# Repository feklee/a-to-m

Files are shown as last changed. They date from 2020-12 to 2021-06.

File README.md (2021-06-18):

Introduction
============

A-to-M is an experimental construction system: Atoms (*A*) are
assembled *to* form molecules (*M*).

A molecule is powered with a USB-C adapter. This adapter is also used
to program individual atoms.

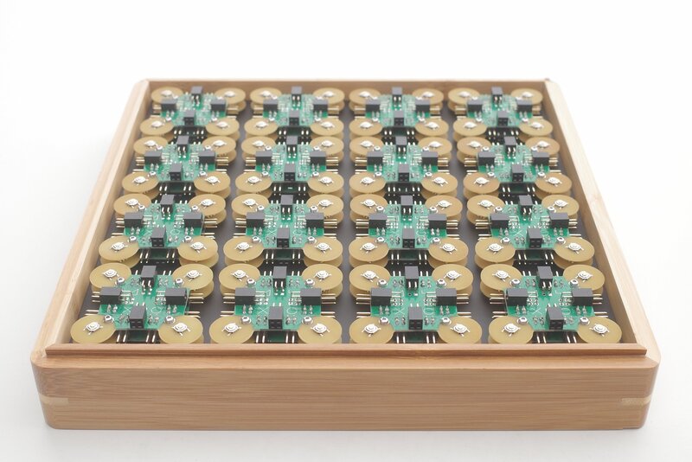
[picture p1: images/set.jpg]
Set


Design guidelines
=================

For areas without solder mask, don’t use components smaller than 0603
and don’t put traces too close. A clearance of 0.35 mm is good.

MiniCore
========

For a good experience, i.e. fast power up of an atom upon connection,
install [MiniCore][1] as boot loader.

Examples
========

Atomic tree
-----------

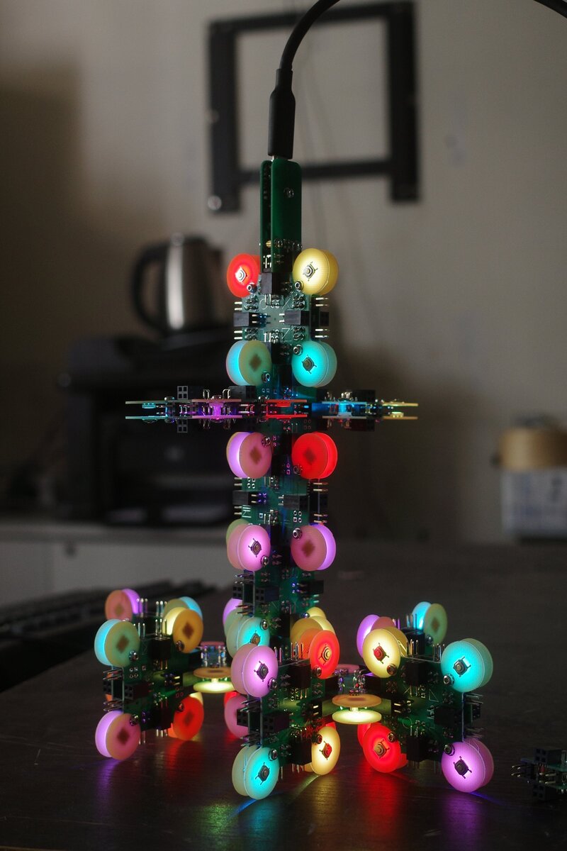
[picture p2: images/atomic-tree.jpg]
Atomic tree


Sequencer
---------

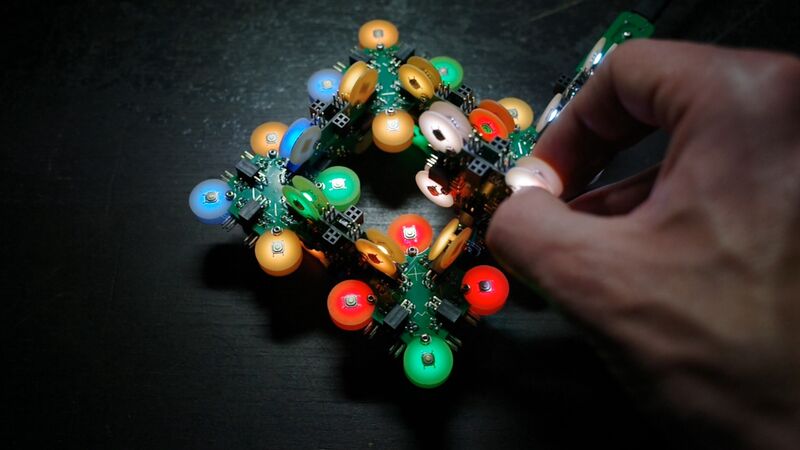
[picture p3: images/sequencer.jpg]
Sequencer
[][2]  
[Video][2]

License
=======

Except where noted otherwise, files are licensed under the WTFPL.

Copyright © 2020 [Felix E. Klee](felix.klee@inka.de)

This work is free. You can redistribute it and/or modify it under the
terms of the Do What The Fuck You Want To Public License, Version 2,
as published by Sam Hocevar. See the COPYING file for more details.

[1]: https://github.com/MCUdude/MiniCore
[2]: https://archive.org/details/a-to-m-sequencer

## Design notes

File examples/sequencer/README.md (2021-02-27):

Example of a simple sequencer. Connect atoms, then push two buttons
simultaneously on the first atom to send a pulse through the network.
It propagates at a rate of 240 beats per atom. Each atom that is
pulsed, plays a note. Configure the note by pushing the buttons on an
atom.

Buttons:

  * Release multiple: Create a pulse propagating through the network.
  
  * Button 1: Increase note.

  * Button 2: Change duration.
  
  * Button 3: Decrease note.
  
  * Button 4: Change waveform.

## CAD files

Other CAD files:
adapter.3dm
atom.3dm

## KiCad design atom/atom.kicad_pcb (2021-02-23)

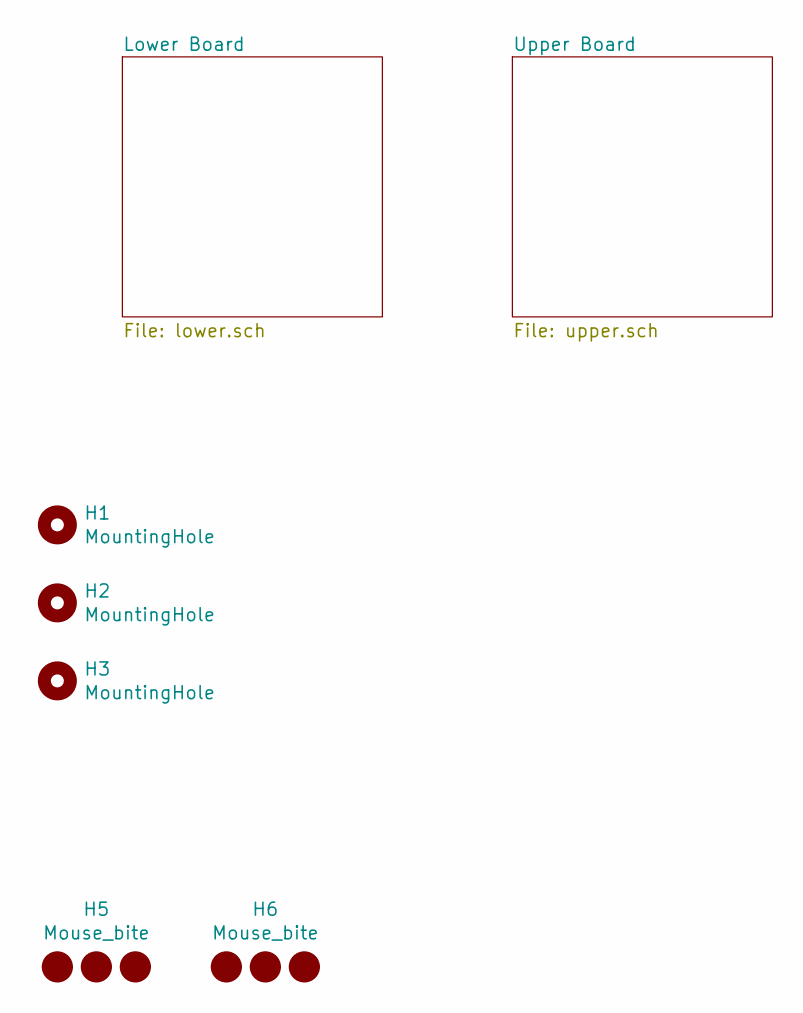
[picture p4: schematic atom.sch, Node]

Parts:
H1, H2, H3: MountingHole; JLCPCB-tooling-hole; JLCPCB BOM False
H5, H6: Mouse_bite; single_sided_tab_5mm; JLCPCB BOM False

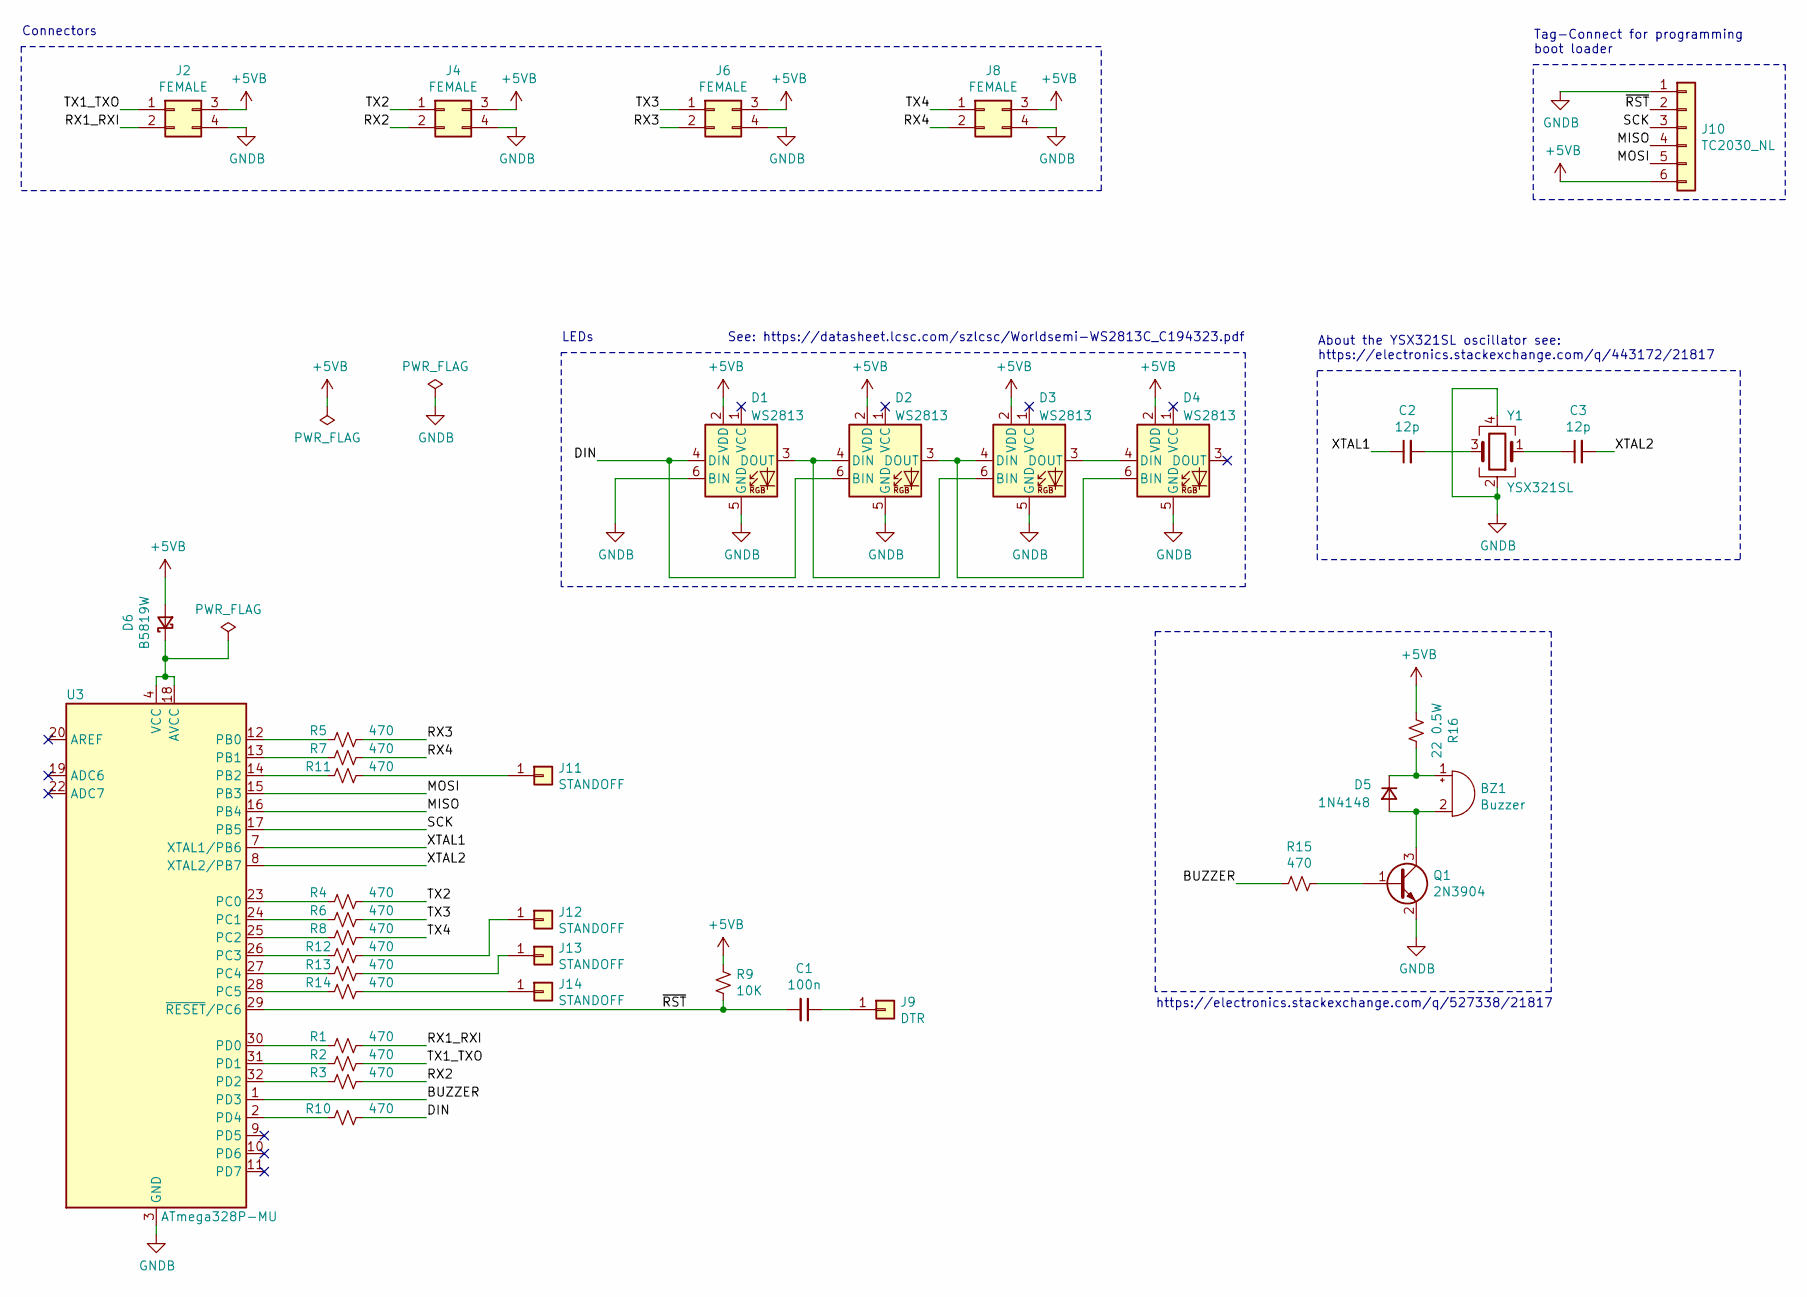
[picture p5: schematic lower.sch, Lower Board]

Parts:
BZ1: Buzzer; MLT-5020; MPN MLT-5020; LCSC Part C94598
C1: 100n; C_0402_1005Metric; MPN CL05B104KO5NNNC; LCSC Part C1525
C2, C3: 12p; C_0402_1005Metric; MPN 0402CG120J500NT; LCSC Part C1547
D1, D2, D3, D4: WS2813; bottom-leaf; MPN WS2813C; LCSC Part C194323
D5: 1N4148; D_SOD-323; MPN 1N4148WS-7-F; LCSC Part C60580
D6: B5819W; D_SOD-123
J2, J4, J6, J8: FEMALE; PinSocket_2x02_P2.54mm_Horizontal; MPN A2541HWR-2x2P; LCSC Part C239353
J9: DTR; PinHeader_1x01_P2.54mm_Vertical; JLCPCB BOM False
J10: TC2030_NL; Tag-Connect_TC2030-IDC-NL_2x03_P1.27mm_Vertical; JLCPCB BOM False
J11, J12, J13, J14: STANDOFF; MountingHole_2.2mm_M2_Pad_Via; JLCPCB BOM False
Q1: 2N3904; SOT-23; MPN PMBT3904,215; LCSC Part C8667
R1, R2, R3, R4, R5, R6, R7, R8, R10, R11, R12, R13, R14, R15: 470; R_0402_1005Metric; MPN 0402WGF4700TCE; LCSC Part C25117
R9: 10K; R_0402_1005Metric; MPN 0402WGF1002TCE; LCSC Part C25744
R16: 22 0.5W; R_2010_5025Metric; MPN 2010W2F220JT4S; LCSC Part C70404
U3: ATmega328P-MU; QFN-32-1EP_5x5mm_P0.5mm_EP3.1x3.1mm; MPN ATMEGA328P-MU; LCSC Part C783592
Y1: YSX321SL; MPN X322516MOB4SI; LCSC Part C12668

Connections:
+5VB: D1.2 (VDD), D2.2 (VDD), D3.2 (VDD), D4.2 (VDD), D6.2 (A), J2.3, J4.3, J6.3, J8.3, J10.6, R9.1, R16.2
/Lower Board/BUZZER: R15.2, U3.1 (PD3)
/Lower Board/DIN: D1.4 (DIN), D2.6 (BIN), R10.1
/Lower Board/MISO: J10.4, U3.16 (PB4)
/Lower Board/MOSI: J10.5, U3.15 (PB3)
/Lower Board/RX1_RXI: J2.2, R1.1
/Lower Board/RX2: J4.2, R3.1
/Lower Board/RX3: J6.2, R5.1
/Lower Board/RX4: J8.2, R7.1
/Lower Board/SCK: J10.3, U3.17 (PB5)
/Lower Board/TX1_TXO: J2.1, R2.1
/Lower Board/TX2: J4.1, R4.1
/Lower Board/TX3: J6.1, R6.1
/Lower Board/TX4: J8.1, R8.1
/Lower Board/XTAL1: C2.1, U3.7 (XTAL1/PB6)
/Lower Board/XTAL2: C3.2, U3.8 (XTAL2/PB7)
/Lower Board/~RST: C1.2, J10.2, R9.2, U3.29 (~RESET~/PC6)
GNDB: D1.5 (GND), D1.6 (BIN), D2.5 (GND), D3.5 (GND), D4.5 (GND), J2.4, J4.4, J6.4, J8.4, J10.1, Q1.2 (E), U3.3 (GND), U3.5 (GND), U3.21 (GND), U3.33 (GND), Y1.2, Y1.4
unnamed: BZ1.1 (-), D5.1 (K), R16.1
unnamed: BZ1.2 (+), D5.2 (A), Q1.3 (C)
unnamed: C1.1, J9.1
unnamed: C2.2, Y1.3
unnamed: C3.1, Y1.1
unnamed: D1.3 (DOUT), D2.4 (DIN), D3.6 (BIN)
unnamed: D2.3 (DOUT), D3.4 (DIN), D4.6 (BIN)
unnamed: D3.3 (DOUT), D4.4 (DIN)
unnamed: D6.1 (K), U3.4 (VCC), U3.6 (VCC), U3.18 (AVCC)
unnamed: J11.1, R11.1
unnamed: J12.1, R12.1
unnamed: J13.1, R13.1
unnamed: J14.1, R14.1
unnamed: Q1.1 (B), R15.1
unnamed: R1.2, U3.30 (PD0)
unnamed: R2.2, U3.31 (PD1)
unnamed: R3.2, U3.32 (PD2)
unnamed: R4.2, U3.23 (PC0)
unnamed: R5.2, U3.12 (PB0)
unnamed: R6.2, U3.24 (PC1)
unnamed: R7.2, U3.13 (PB1)
unnamed: R8.2, U3.25 (PC2)
unnamed: R10.2, U3.2 (PD4)
unnamed: R11.2, U3.14 (PB2)
unnamed: R12.2, U3.26 (PC3)
unnamed: R13.2, U3.27 (PC4)
unnamed: R14.2, U3.28 (PC5)

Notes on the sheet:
See: https://datasheet.lcsc.com/szlcsc/Worldsemi-WS2813C_C194323.pdf
LEDs
Connectors
About the YSX321SL oscillator see: https://electronics.stackexchange.com/q/443172/21817
Tag-Connect for programming boot loader
https://electronics.stackexchange.com/q/527338/21817

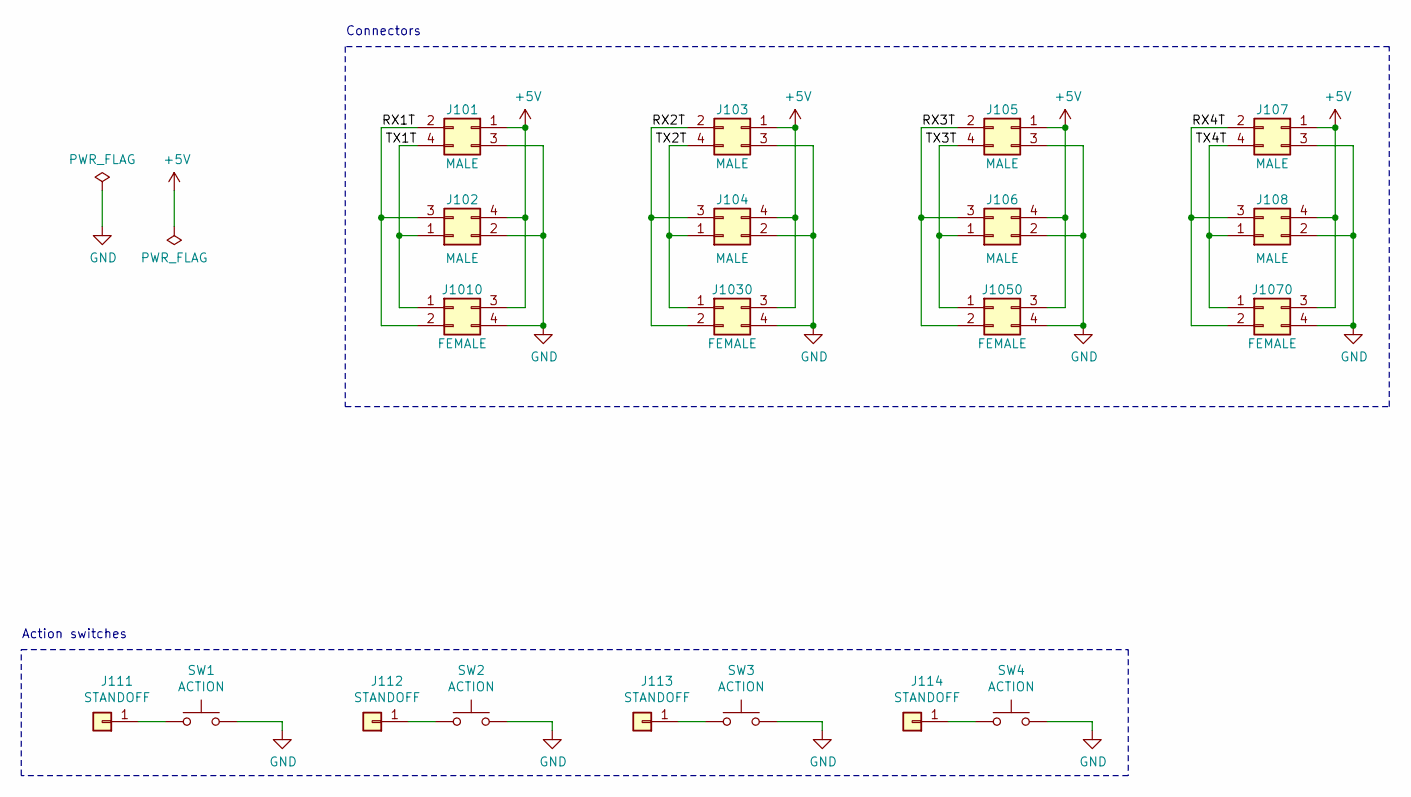
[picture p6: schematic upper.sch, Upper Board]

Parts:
J101, J103, J105, J107, J1010, J1030, J1050, J1070: MALE; PinHeader_2x02_P2.54mm_Horizontal; MPN A2541WR-2x2P; LCSC Part C239333
J102, J104, J106, J108: FEMALE; PinSocket_2x02_P2.54mm_Horizontal; MPN A2541HWR-2x2P; LCSC Part C239353
J111, J112, J113, J114: STANDOFF; MountingHole_2.2mm_M2_Pad_Via; JLCPCB BOM False
SW1, SW2, SW3, SW4: ACTION; top-leaf; MPN TS-1187A-B-A-B; LCSC Part C318884

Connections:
+5V: J101.1, J102.3, J103.1, J104.3, J105.1, J106.3, J107.1, J108.3, J1010.4, J1030.4, J1050.4, J1070.4
/Upper Board/RX1T: J101.2, J102.2, J1010.3
/Upper Board/RX2T: J103.2, J104.2, J1030.3
/Upper Board/RX3T: J105.2, J106.2, J1050.3
/Upper Board/RX4T: J107.2, J108.2, J1070.3
/Upper Board/TX1T: J101.4, J102.1, J1010.1
/Upper Board/TX2T: J103.4, J104.1, J1030.1
/Upper Board/TX3T: J105.4, J106.1, J1050.1
/Upper Board/TX4T: J107.4, J108.1, J1070.1
GND: J101.3, J102.4, J103.3, J104.4, J105.3, J106.4, J107.3, J108.4, J1010.2, J1030.2, J1050.2, J1070.2, SW1.2, SW2.2, SW3.2, SW4.2
unnamed: J111.1, SW1.1
unnamed: J112.1, SW2.1
unnamed: J113.1, SW3.1
unnamed: J114.1, SW4.1

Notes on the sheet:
Action switches
Connectors

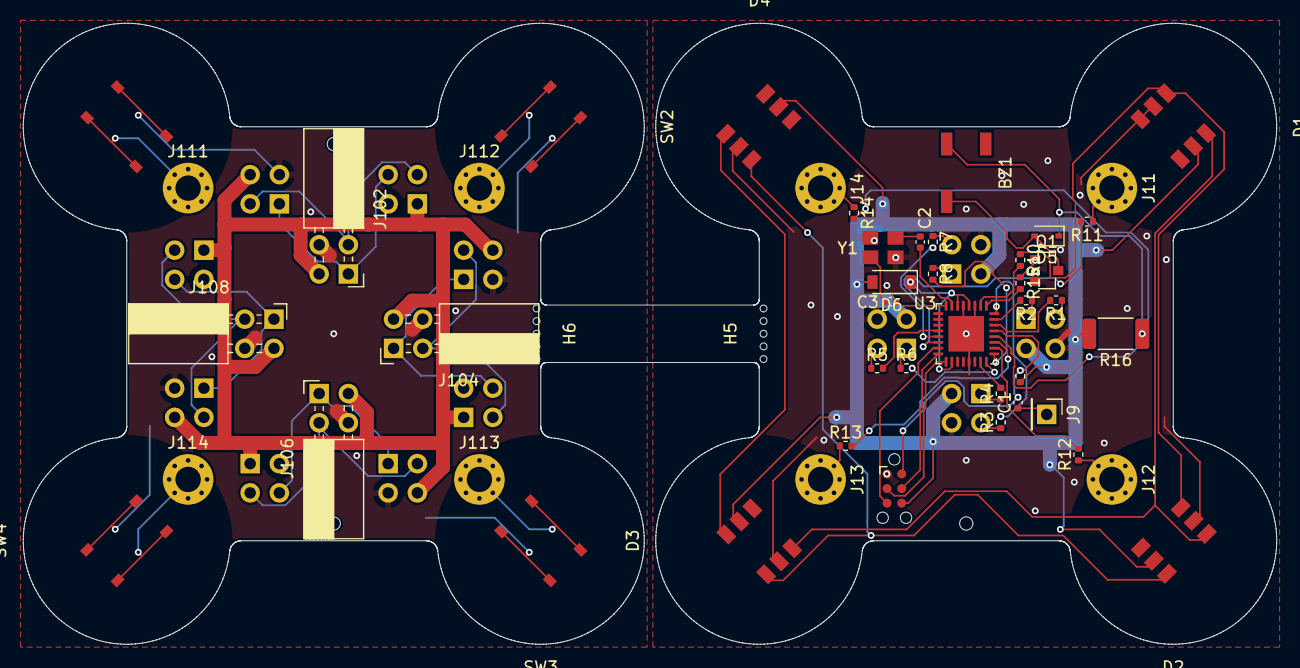
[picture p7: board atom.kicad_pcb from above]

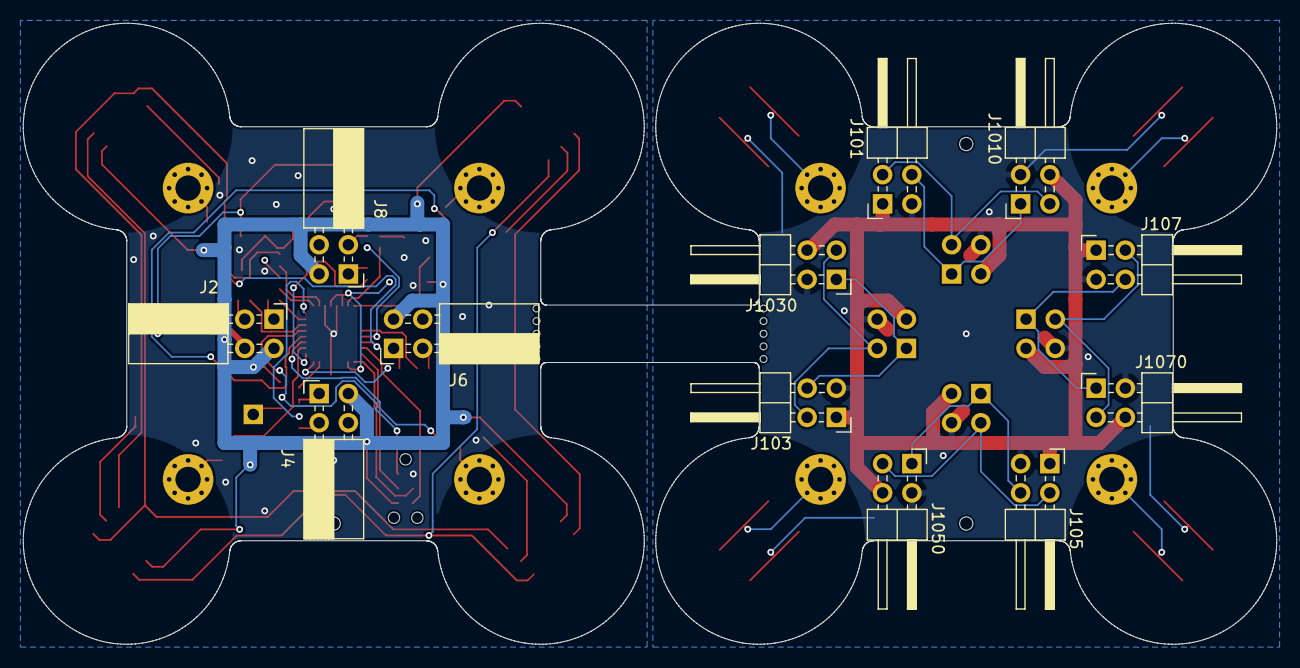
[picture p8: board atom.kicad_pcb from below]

Board: 2 copper layers, 109.0 x 54.0 mm, 64 parts (12 on the bottom side), 59 nets.

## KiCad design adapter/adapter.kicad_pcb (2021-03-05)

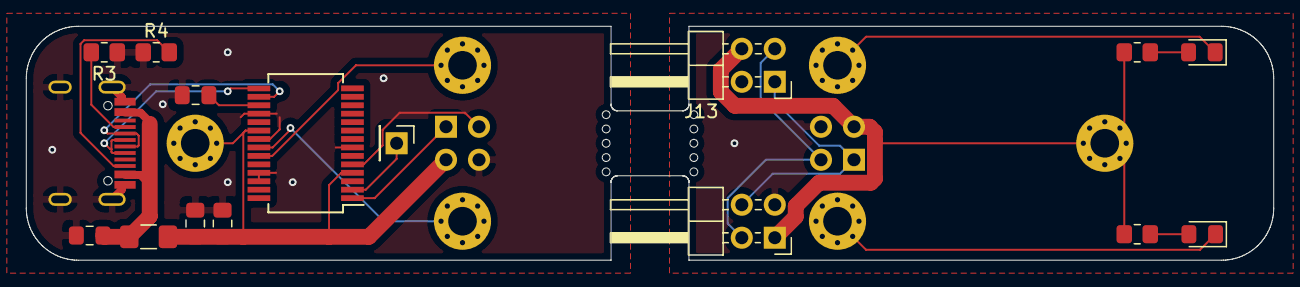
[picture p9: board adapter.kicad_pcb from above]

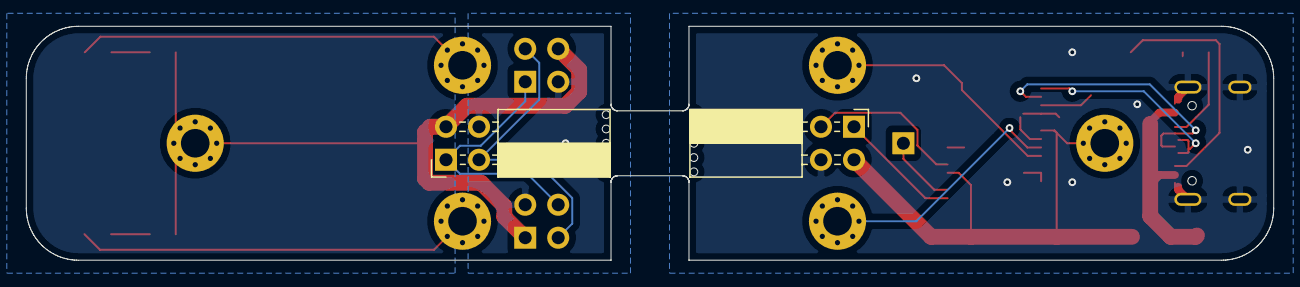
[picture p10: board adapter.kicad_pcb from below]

Board: 2 copper layers, 96.0 x 18.0 mm, 26 parts (2 on the bottom side), 21 nets.

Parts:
C1, C2, C3: 100n; C_0805_2012Metric_Pad1.15x1.40mm_HandSolder
C4: 4.7u; C_0805_2012Metric_Pad1.15x1.40mm_HandSolder
D1: Green; LED_0805_2012Metric_Pad1.15x1.40mm_HandSolder
D2: Red; LED_0805_2012Metric_Pad1.15x1.40mm_HandSolder
F1: Polyfuse_Small; Fuse_1206_3216Metric_Pad1.42x1.75mm_HandSolder
H1, H2: Mouse_bite; single_sided_tab_5mm
J2, J12: FEMALE; PinSocket_2x02_P2.54mm_Horizontal
J3, J4, J5, J14, J15, J16: STANDOFF; MountingHole_2.2mm_M2_Pad_Via
J6: USB_C_Receptacle_USB2.0; SOFNG_MC-311D
J7: DTR; PinHeader_1x01_P2.54mm_Vertical
J11, J13: MALE; PinHeader_2x02_P2.54mm_Horizontal
R1, R2: 1k; R_0805_2012Metric_Pad1.20x1.40mm_HandSolder
R3, R4: 5.1k; R_0805_2012Metric_Pad1.20x1.40mm_HandSolder
U1: FT232RL; SSOP-28_5.3x10.2mm_P0.65mm

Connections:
+5V: J11.1, J12.3, J13.4, J16.1, R1.1, R2.1
+5VB: C3.2, C4.1, F1.1, J2.3, J5.1, U1.4, U1.20
/Lower Board/D+: J6.A6, J6.B6, U1.15
/Lower Board/D-: J6.A7, J6.B7, U1.16
/Lower Board/DTR: J7.1, U1.2
/Lower Board/RXD: J2.2, U1.5
/Lower Board/RXLED: J4.1, U1.22
/Lower Board/TXD: J2.1, U1.1
/Lower Board/TXLED: J3.1, U1.23
/Lower Board/VBUS: C1.2, F1.2, J6.A4, J6.A9, J6.B4, J6.B9
/Upper Board/RX1T: J11.2, J12.2, J13.3
/Upper Board/TX1T: J11.4, J12.1, J13.1
GND: J11.3, J12.4, J13.2
GNDB: C1.1, C2.2, C3.1, C4.2, J2.4, J6.A1, J6.A12, J6.B1, J6.B12, J6.S1, R3.1, R4.1, U1.7, U1.18, U1.21, U1.25, U1.26
unnamed: C2.1, U1.17
unnamed: D1.1, J14.1
unnamed: D1.2, R1.2
unnamed: D2.1, J15.1
unnamed: D2.2, R2.2
unnamed: J6.A5, R3.2
unnamed: J6.B5, R4.2

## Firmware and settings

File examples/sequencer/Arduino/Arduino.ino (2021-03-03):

#include <FastLED.h>
#include <ezButton.h>

constexpr uint8_t buttonPinNos[] = {
  10, // PB2
  17, // PC3
  18, // PC4
  19 // PC5
};

constexpr uint8_t rxPinNos[] = {
  0, // RX1 = PD0 = PCINT16
  2, // RX2 = PD2 = PCINT18
  8, // RX3 = PB0 = PCINT0
  9 // RX4 = PB1 = PCINT1
};

constexpr uint8_t txPinNos[] = {
  1, // TX1 = PD1
  A0, // TX2 = PC0
  A1, // TX3 = PC1
  A2 // TX4 = PC2
};

constexpr uint8_t speakerPinNo = 3;

constexpr uint8_t ledPinNo = 4;
CRGB leds[4];

volatile bool pulseHasBeenReceived = false;
volatile uint8_t portThatReceivedPulse;

bool waitingForMultiButtonRelease = false;

constexpr uint8_t noOfDurations = 3;
uint16_t durations[noOfDurations] = { // in ms
  125,
  250,
  375
};
int8_t selectedDurationIndex = 1;

constexpr uint8_t noOfNotes = 10;
uint16_t frequencies[noOfNotes] = {
  2093, // C7
  2349, // D7
  2637, // E7
  3136, // G7
  3520, // A7
  4186, // C8
  4699, // D8
  5274, // E8
  6272, // G8
  7040 // A8
};
uint8_t selectedNote = 5;

constexpr uint8_t noOfWaveForms = 3;
struct {
  enum {silent, square, noise};
} waveForms;
uint8_t selectedWaveForm = waveForms.square;

struct {
  enum {incNote, duration, decNote, waveForm};
} buttonNos;

ezButton buttons[] = {
  {buttonPinNos[0]},
  {buttonPinNos[1]},
  {buttonPinNos[2]},
  {buttonPinNos[3]}
};

uint16_t toggleCount;

void blinkLed(uint8_t i) {
  leds[i].setHSV(255, 0, 255);
  FastLED.show();
  delay(100);
  leds[i].setHSV(255, 0, 0);
  FastLED.show();
}

uint8_t nextDurationIndex() {
  return (selectedDurationIndex + 1) % noOfDurations;
}

uint8_t prevNote() {
  return selectedNote == 0 ? 0 : selectedNote - 1;
}

uint8_t nextNote() {
  return selectedNote == noOfNotes - 1
    ? noOfNotes - 1
    : selectedNote + 1;
}

uint8_t nextWaveForm() {
  return (selectedWaveForm + 1) % noOfWaveForms;
}

CHSV noteColor(uint8_t note) {
  const uint8_t maxNote = noOfNotes - 1;
  return CHSV(uint32_t(note) * 64 / maxNote,
              255 - uint32_t(note) * 255 / maxNote,
              255);
}

CHSV durationColor(uint8_t durationIndex) {
  const uint8_t maxDurationIndex = noOfDurations - 1;
  return CHSV(160 + uint32_t(durationIndex) * 96 / maxDurationIndex,
              255, 255);
}

CHSV waveFormColor(uint8_t waveForm) {
  switch (waveForm) {
  case waveForms.square:
    return CHSV(96, 255, 255);
  case waveForms.noise:
    return CHSV(0, 0, 255);
  case waveForms.silent:
  default:
    return CHSV(0, 0, 0);
  }
}

void showStatusWithLeds() {
  leds[buttonNos.incNote] = noteColor(nextNote());
  leds[buttonNos.decNote] = noteColor(prevNote());
  leds[buttonNos.duration] = durationColor(selectedDurationIndex);
  leds[buttonNos.waveForm] = waveFormColor(selectedWaveForm);
  
  FastLED.show();
}

void blinkAllLeds() {
  for (uint8_t i = 0; i < 4; i ++) {
    leds[i].setHSV(255, 0, 255);
  }
  FastLED.show();
  delay(250);
  showStatusWithLeds();
}

inline void parseSignal(const uint8_t minPinNo,
                        const uint8_t maxPinNo) {
  for (uint8_t i = 0; i < 4; i ++) {
    const uint8_t rxPinNo = rxPinNos[i];
    if (rxPinNo >= minPinNo && rxPinNo <= maxPinNo) {
      if (digitalRead(rxPinNo) == 0) {
        pulseHasBeenReceived = true;
        portThatReceivedPulse = i;
        break;
      }
    }
  }
}

ISR(PCINT2_vect) { // D0-D7
  parseSignal(0, 7);
}

ISR(PCINT0_vect) { // D8-D13
  parseSignal(8, 13);
}

void sendPulseOnTxPin(uint8_t i) {
  uint8_t txPinNo = txPinNos[i];
  digitalWrite(txPinNo, LOW);
  delay(10);
  digitalWrite(txPinNo, HIGH);
}

void sendPulseOnRxPin(uint8_t i) {
  uint8_t rxPinNo = rxPinNos[i];
  disablePinChangeInterrupts();
  pinMode(rxPinNo, OUTPUT);
  digitalWrite(rxPinNo, LOW);
  delay(10);
  digitalWrite(rxPinNo, HIGH);
  pinMode(rxPinNo, INPUT_PULLUP);
  enablePinChangeInterrupts();
}

void enablePinChangeInterrupts() {
  PCICR = // Pin Change Interrupt Control Register
    bit(PCIE2) | // PCINT16 to PCINT23
    bit(PCIE0); // PCINT0 to PCINT7
  PCMSK2 = 0;
  bitWrite(PCMSK2, PCINT18, 1);
  bitWrite(PCMSK2, PCINT16, 1);
  PCMSK0 = 0;
  bitWrite(PCMSK0, PCINT1, 1);
  bitWrite(PCMSK0, PCINT0, 1);
}

void disablePinChangeInterrupts() {
  PCICR = 0;
  PCMSK2 = 0;
  PCMSK0 = 0;
}

void listenOnRxPins() {
  for (uint8_t i = 0; i < 4; i++) {
    pinMode(rxPinNos[i], INPUT_PULLUP);
  }
}

// This code works for RX and TX being crossed over (as it should be)
// and not being crossed over (hardware bug in one of the first test
// productions).
void sendPulseOnOtherPorts(const uint8_t pinNotToPulse) {
  for (uint8_t i = 0; i < 4; i++) {
    if (i != pinNotToPulse) {
      sendPulseOnTxPin(i);
      sendPulseOnRxPin(i); // in case pins are not crossed over
    }
  }
}

void sendPulseOnAllPorts() {
  sendPulseOnOtherPorts(4);
}

// Taken from (and edited):
// https://github.com/ninetreesdesign/randomNumberGenerator
uint16_t rng() {
  static uint16_t y = 0;
  y += (micros() && 0x1FFF); // seeded with changing number
  y ^= y << 2;
  y ^= y >> 7;
  y ^= y << 7;
  return y;
}

ISR(TIMER1_COMPA_vect) {
  if (toggleCount > 0) {
    switch (selectedWaveForm) {
    case waveForms.square:
      PORTD ^= 0b00001000;
      break;
    case waveForms.noise:
      if (rng() & 1) {
        PORTD ^= 0b00001000;
      }
      break;
    }
    toggleCount--;
  } else {
    stopSound();
  }
}

void stopSound() {
  TIMSK1 = 0;
  PORTD &= 0b11110111; // Seen in Arduino tone(), maybe not necessary
}

void playSound(
               uint16_t frequency, // Hz
               uint16_t duration // ms
               ) {
  cli(); // Disable interrupts till everything is configured

  // Timer 1 is a 16-bit timer.

  // Set WGM - Waveform Generation Mode - to CTC (Clear Timer on
  // Compare Match, TOP = OCR1A):
  bitWrite(TCCR1B, WGM13, 0);
  bitWrite(TCCR1B, WGM12, 1);
  bitWrite(TCCR1A, WGM11, 0);
  bitWrite(TCCR1A, WGM10, 0);

  // Disable prescaler:
  bitWrite(TCCR1B, CS12, 0);
  bitWrite(TCCR1B, CS11, 0);
  bitWrite(TCCR1B, CS10, 1);

  // Define how often to call the interrupt:
  OCR1A = F_CPU / frequency / 2;

  // Make ISR(TIMER2_COMPA_vect) be called when timer reaches TOP:
  bitWrite(TIMSK1, OCIE1A, 1);

  toggleCount = 2ul * frequency * duration / 1000;

  sei();
}

void playSelectedSound() {
  playSound(frequencies[selectedNote],
            durations[selectedDurationIndex]);
}

void debounceButtons() {
  for (uint8_t i = 0; i < 4; i++) {
    buttons[i].setDebounceTime(50);
  }
}

void enableTxPins() {
  for (uint8_t i = 0; i < 4; i++) {
      pinMode(txPinNos[i], OUTPUT);
  }
}

void setup() {
  FastLED.addLeds<WS2813, ledPinNo, GRB>(leds, 4).
    setCorrection(TypicalLEDStrip);
  FastLED.setBrightness(255);
  showStatusWithLeds();

  debounceButtons();

  enableTxPins();
  listenOnRxPins();
  enablePinChangeInterrupts();
}

void loopButtons() {
  for (uint8_t i = 0; i < 4; i++) {
    buttons[i].loop();
  }
}

uint8_t noOfButtonsPressed() {
  uint8_t no = 0;
  for (uint8_t i = 0; i < 4; i++) {
    if (buttons[i].getState() == LOW) {
      no++;
    }
  }
  return no;
}

bool multipleButtonsHaveBeenReleased() {
  if (!waitingForMultiButtonRelease) {
    if (noOfButtonsPressed() > 1) {
      waitingForMultiButtonRelease = true;
    }
    return false;
  }

  if (noOfButtonsPressed() == 0) {
    waitingForMultiButtonRelease = false;
    return true;
  }

  return false;
}

void parseSingleButtonReleases() {
  bool aButtonHasBeenReleased = false;

  if (buttons[buttonNos.incNote].isReleased()) {
    selectedNote = nextNote();
    aButtonHasBeenReleased = true;
  }

  if (buttons[buttonNos.decNote].isReleased()) {
    selectedNote = prevNote();
    aButtonHasBeenReleased = true;
  }

  if (buttons[buttonNos.duration].isReleased()) {
    selectedDurationIndex = nextDurationIndex();
    aButtonHasBeenReleased = true;
  }

  if (buttons[buttonNos.waveForm].isReleased()) {
    selectedWaveForm = nextWaveForm();
    aButtonHasBeenReleased = true;
  }

  if (aButtonHasBeenReleased) {
    showStatusWithLeds();
    playSelectedSound();
  }
}

void parseButtons() {
  if (multipleButtonsHaveBeenReleased()) {
    sendPulseOnAllPorts();
    return;
  }

  if (waitingForMultiButtonRelease) {
    return;
  }

  parseSingleButtonReleases();
}

void loop() {
  if (pulseHasBeenReceived) {
    playSelectedSound();
    blinkAllLeds();
    sendPulseOnOtherPorts(portThatReceivedPulse);
    pulseHasBeenReceived = false;
  }

  loopButtons();
  parseButtons();
}

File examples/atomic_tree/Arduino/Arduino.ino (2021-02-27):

#include <FastLED.h>

#define LED_PIN     4
#define NUM_LEDS    4
#define BRIGHTNESS  255
#define LED_TYPE    WS2813
#define COLOR_ORDER GRB
CRGB leds[NUM_LEDS];
uint8_t hues[NUM_LEDS];

void setup() {
  FastLED.addLeds<LED_TYPE, LED_PIN, COLOR_ORDER>(leds, NUM_LEDS).setCorrection( TypicalLEDStrip );
  FastLED.setBrightness(BRIGHTNESS);

  for (int i = 0; i < 4; i++) {
    hues[i] = i * 64;
  }
}

void loop() {
  for (int i = 0; i < 500; i++) {
    for (int j = 0; j < 4; j++) {
      hues[j] += 10;
      uint8_t hue = (random8() < 10) ? 255 : hues[j];
      leds[j].setHSV(hue, 255, 255);
    }
    FastLED.show();
    delay(50);
  }
}

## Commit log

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2020-10-13 Assign footprints and complete BOM
    [bottom.sch, draft.sch, top.sch]
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2020-10-14 Add buzzer and clean up
    [bottom.sch, draft.kicad_pcb, draft.sch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]
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2020-10-16 Precisely position some components
    [draft.kicad_pcb]
2020-10-16 Create layout for KiCad
    [shape.3dm]
2020-10-16 Select transistor for buzzer
    [bottom.sch, draft.kicad_pcb]
2020-10-16 Fix: Wrong footprint for transistor
    [bottom.sch, draft.kicad_pcb]
2020-10-16 Fix: Missing and conflicting values in symbol table
    [bottom.sch]
2020-10-16 Add footprint for diode
    [bottom.sch, draft.kicad_pcb]
2020-10-16 Add footprint for buzzer
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2020-10-21 Play with shape / design
    [draft.kicad_pcb, shape.3dm]
2020-10-21 Give project more mature name
    [pcb.kicad_pcb, pcb.sch]
2020-10-21 Update solder mask keep out
    [pcb.kicad_pcb, top.sch]
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2020-10-21 Add copper pour keep-out zones for top board
    [pcb.FCStd, pcb.kicad_pcb]
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2020-10-22 Reduce footprint of tab
    [pcb.kicad_pcb, shape.3dm]
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2020-10-22 Switch to WS2813C (bigger footprint)
    [bottom.sch]
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2020-10-22 Assign bottom-leaf footprints to LEDs
    [bottom.sch]
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2020-10-22 Round power for bottom
    [pcb.kicad_pcb]
2020-10-22 Route top board (but DRC errors)
    [pcb.kicad_pcb]
2020-10-22 Fix: overlapping fill zones
    [pcb.kicad_pcb]
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2020-10-22 Fix: Unconnected GND
    [pcb.kicad_pcb]
2020-10-22 Fix: unconnected fill zones
    [pcb.kicad_pcb]
2020-10-22 Fix: Track too close to via
    [pcb.kicad_pcb]
2020-10-22 Fix: Drill holes in mouse bite too close
    [pcb.kicad_pcb]
2020-10-28 Fix: Tag-Connect cannot be pushed through holes
    [pcb.FCStd, pcb.kicad_pcb]
2020-10-28 Fix: Small resistor not in solder mask area
    [pcb.kicad_pcb]
2020-10-29 Move holes for headers 0.1 mm inwards
    [pcb.kicad_pcb, shape.3dm]
2020-10-29 Make Tag-Connect easier accessible
    [pcb.kicad_pcb]
2020-10-29 Fix: DRC errors
    [pcb.kicad_pcb]
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2020-10-30 Rename top/bottom to avoid confusion with layers
    [lower.sch, pcb.sch, upper.sch]
2020-10-30 Resize sheets for consistency
    [pcb.sch]
2020-10-30 Add schematic for adapter
    [adapter.kicad_pcb, adapter.sch, lower.sch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]
2020-10-30 Add resettable fuse (don’t connect yet)
    [lower.sch]
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2020-10-30 Fix: Nested redundancy
    [adapter.kicad_pcb, adapter.sch, lower.sch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]
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2020-11-03 Route new resistor package
    [pcb.kicad_pcb]
2020-11-03 Experiment: Add text to label buttons
    [pcb.kicad_pcb]
2020-11-03 Experimental: Change button labels to dots
    [shape.3dm]
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2020-11-05 Retrace to accommodate for changed footprint
    [pcb.kicad_pcb]
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2020-11-05 Fix: Wrong pin order
    [lower.sch]
2020-11-05 Fix: Wrong labels
    [lower.sch]
2020-11-06 Reroute, add my chop
    [pcb.kicad_pcb]
2020-11-06 Remove outdated user drawings
    [pcb.kicad_pcb]
2020-11-06 Move TX3/RX3 resistors closer to pin holes
    [pcb.kicad_pcb]
2020-11-06 Move RX2/TX2 closer to respective holes
    [pcb.kicad_pcb]
2020-11-06 Make space for chop
    [pcb.kicad_pcb]
2020-11-06 Swap sides to move mouse bites in safer position
    [pcb.kicad_pcb]
2020-11-06 Fix DRC errors
    [pcb.kicad_pcb]
2020-11-06 Swap sides, update edge cuts
    [shape.3dm]
2020-11-06 15 → 22 Ω for safety and to avoid clipping
    [lower.sch, pcb.kicad_pcb]
2020-11-06 Fix: Wrong pin order in upper board
    [upper.sch]
2020-11-06 Fix: UIDs of connectors changed
    [upper.sch]
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2020-11-06 Change to parts available for JLCPCB PCBA
    [lower.sch]
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2020-11-06 Incorporate JLCPCB tooling holes
    [pcb.kicad_pcb]
2020-11-06 Fix: Non connected GNDB areas
    [pcb.kicad_pcb]
2020-11-07 Hide tooling holes under female headers
    [pcb.kicad_pcb]
2020-11-07 Flip FTDI connector inward for protection
    [pcb.kicad_pcb]
2020-11-07 Model new board edge cuts in 3D
    [shape.3dm]
2020-11-10 Make fields compatible with JLCPCB BOM plugin
    [lower.sch, upper.sch]
2020-11-10 Update footprints (some falsely not marked as SMD)
    [pcb.kicad_pcb]
2020-11-12 Insert wider mouse bites to match JLCPCB capabil.
    [pcb.kicad_pcb]
2020-11-12 Add tooling holes to schematic
    [pcb.kicad_pcb, pcb.sch]
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2020-11-12 Replace footprints without schematic symbol
    [pcb.kicad_pcb]
2020-11-12 Modify outline for new mouse bites
    [shape.3dm]
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2020-11-19 Draft design for adapter
    [adapter.3dm]
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2020-11-19 Change female headers to horizontal
    [lower.sch, upper.sch]
2020-11-19 Use 1206 pad for fuse
    [lower.sch]
2020-11-19 Set clearance for holes
2020-11-19 Put footprints on layout
    [adapter.kicad_pcb]
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2020-11-19 Add holes for standoffs
    [adapter.kicad_pcb, lower.sch, upper.sch]
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2020-11-19 Add edge cuts and roughly place components
    [adapter.kicad_pcb]
2020-11-19 Model in 3D and define positions
    [adapter.3dm]
2020-11-19 Define positions of additional standoffs
    [adapter.3dm]
2020-11-19 Position connectors and standoff holes
    [adapter.kicad_pcb]
2020-11-19 Define positions for LEDs
    [adapter.3dm]
2020-11-19 Move LEDs to upper board
    [lower.sch, upper.sch]
2020-11-19 Move LEDs to safer place
    [adapter.3dm]
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2020-11-19 Add footprints for mouse bites
    [adapter.kicad_pcb]
2020-11-20 Use different power net names for lower board
    [lower.sch]
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2020-11-20 Configure Gerber export options
    [adapter.kicad_pcb]
2020-11-20 Move around component positions
    [adapter.3dm]
2020-11-23 Fix: Wrong pin numbering of transistor
    [lower.sch]
2020-11-23 Fix: Wrong pinout for transistor
    [pcb.kicad_pcb]
2020-11-23 Change order of A-T-O-M
    [pcb.kicad_pcb]
2020-11-25 Move around text on F.Fab layer
    [adapter.kicad_pcb]
2020-11-25 Make interesting values visible on F.Fab
    [adapter.kicad_pcb]
2020-11-26 Add 56k pullups to fake USB host signature
    [lower.sch]
2020-11-26 Put +5V on standoff: Make LEDs work w/o connection
    [lower.sch, upper.sch]
2020-11-26 Add power flags to pass DRC check
    [lower.sch, upper.sch]
2020-11-26 Assign footprints to pullups
    [lower.sch]
2020-11-26 Add new footprints, connect upper standoff
    [adapter.kicad_pcb]
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2020-11-26 Update USB receptacle footprint
    [adapter.kicad_pcb]
2020-11-27 Finish routing following changes
    [adapter.kicad_pcb]
2020-11-27 Hide mouse bites under female headers
    [pcb.3dm, pcb.kicad_pcb]
2020-11-27 Specify and wire up Schottky diode
    [lower.sch]
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2020-11-27 Add temporary fix for: upper+lower not bridged
    [pcb.FCStd, pcb.kicad_pcb, pcb.sch]
2020-11-28 Move all male headers to upper board
    [pcb.3dm]
2020-11-28 Fix fix: Wrong wiring for new males
    [pcb.kicad_pcb, pcb.sch, upper.sch]
2020-12-02 Add mounting holes for PCBA
    [pcb.kicad_pcb, pcb.sch]
2020-12-03 Move values to make nicer print
    [adapter.kicad_pcb]
2020-12-04 Fix: Adapter identif. as down- instead of upstream
    [lower.sch]
2020-12-04 Reroute to reflect fix
    [adapter.kicad_pcb]
2020-12-05 Move male headers to upper board
    [adapter.3dm]
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2020-12-05 Create alternative upper adapter board as fix
    [adapter.kicad_pcb, adapter.sch, upper.sch]
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2020-12-05 Update positions for new footprints + orientation
    [adapter.3dm]
2020-12-05 Move footprints to exact positions
    [adapter.kicad_pcb]
2020-12-08 Fix: Connectors on wrong side
    [adapter.3dm]
2020-12-09 Fix pinout
    [adapter.kicad_pcb, lower.sch, upper.sch]
2020-12-09 Remove fix which is not needed anymore
    [adapter.kicad_pcb, adapter.sch, upper.sch]
2020-12-09 Fix bridging: Move male headers to upper board
    [lower.sch, upper.sch]
2020-12-09 Add missing power flag
    [lower.sch]
2020-12-09 Remove fix, after merging it in PCB
    [pcb.FCStd, pcb.kicad_pcb, pcb.sch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]
2020-12-09 The PCB is an atom
    [atom.3dm, lower.sch, pcb.FCStd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]
2020-12-10 Clean up and rename: PCB -> atom
    [atom.kicad_pcb, atom.sch, lower.sch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]
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2020-12-11 Fix: USB-C port no configured as downstream
    [adapter.kicad_pcb, lower.sch]
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2021-02-18 Fix: TX matched against TX, not RX
    [atom.3dm]
2021-02-18 Fix: Labels for RX/TX for male headers swapped
    [atom.3dm]
2021-02-18 Fix: RX needs to be connected to TX
    [upper.sch]
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2021-02-18 Create separate fix for past design
    [fix.kicad_pcb]
2021-02-18 Remove temporary fix (ordered)
    [fix.kicad_pcb]
2021-02-19 Fix: Durations colors upside down
    [Arduino.ino]
2021-02-19 Add noise wave form
    [Arduino.ino]
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2021-02-22 Mention not to put traces too close
2021-02-22 Add clearance to footprints without solder mask
    [atom.kicad_pcb]
2021-02-22 Move pads slightly inward, to match data sheet
    [atom.kicad_pcb]
2021-02-22 Shrink unnecessarily large clearance
    [atom.kicad_pcb]
2021-02-22 Reroute to accommodate larger clearance
    [atom.kicad_pcb]
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2021-03-03 Make it work w/ crossed over pins (correct wiring)
    [Arduino.ino]
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2021-03-05 Match adapter colors and labels to that of an atom
    [adapter.3dm]
2021-03-05 Swap yellow / green for lower board
    [adapter.3dm]
2021-03-05 Fix RX/TX assignment lower board
    [adapter.3dm]
2021-03-05 Swap RX/TX on lower board
    [adapter.kicad_pcb, lower.sch]
